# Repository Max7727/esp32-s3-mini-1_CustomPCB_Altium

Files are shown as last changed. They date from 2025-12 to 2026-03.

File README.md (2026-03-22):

# esp32-s3-mini-1_CustomPCB_Altium
Integrating an ESP32-S3-Mini-1 module into a custom PCB design

ESP32-S3-MINI-1 module - (Xtensa® dual-core 32-bit LX7) featuring 2.4 GHz Wi-Fi and Bluetooth 5 (LE).

I designed a custom PCB, centered around ESP32-S3-MINI-1 module based on reference schematics and guidelines from official manufactoror and various diffrent datasheets.

Used 4-layer stackup to provide dedicated GND planes for EMI shielding. Completed full manual route of all components, applied clearances and most common rules in PCB desing (including "rooms" altium special feature).

Features and capabilities:
* Digital communication - dual-interface: USB-C to UART bridge and USB-C to esp32 (ESP32-S3's native USB OTG capability)
* Power management - stable 3.3V power trace using a LDO Regulator, implemented polygon pours for both power and GND.
* ESD protection circuits- TVS diode protection to protect the internal silicon from electrostatic.
* 24-pin headers (Header 1x24) providing access to the full suite of GPIOs, SPI, I2C, and PWM pins.
* On-board status LEDs and tactile boot and reset switches
* Boot/reset circuits using NPN transistors.
* Dual Power Input Protection - designed the power stage to safely handle power from the USB-C connector while maintaining thermal stability through the LDO regulator ???
* Differential Pair Implementation (Impedance Control) - controlled trace lengths and widths to maintain target impedance 90 ohms, in order to reject common-mode noise and reduce EMI radiation.

* **Check out the description for commits for more details on the work process.**

# Schematics

<p align="center">
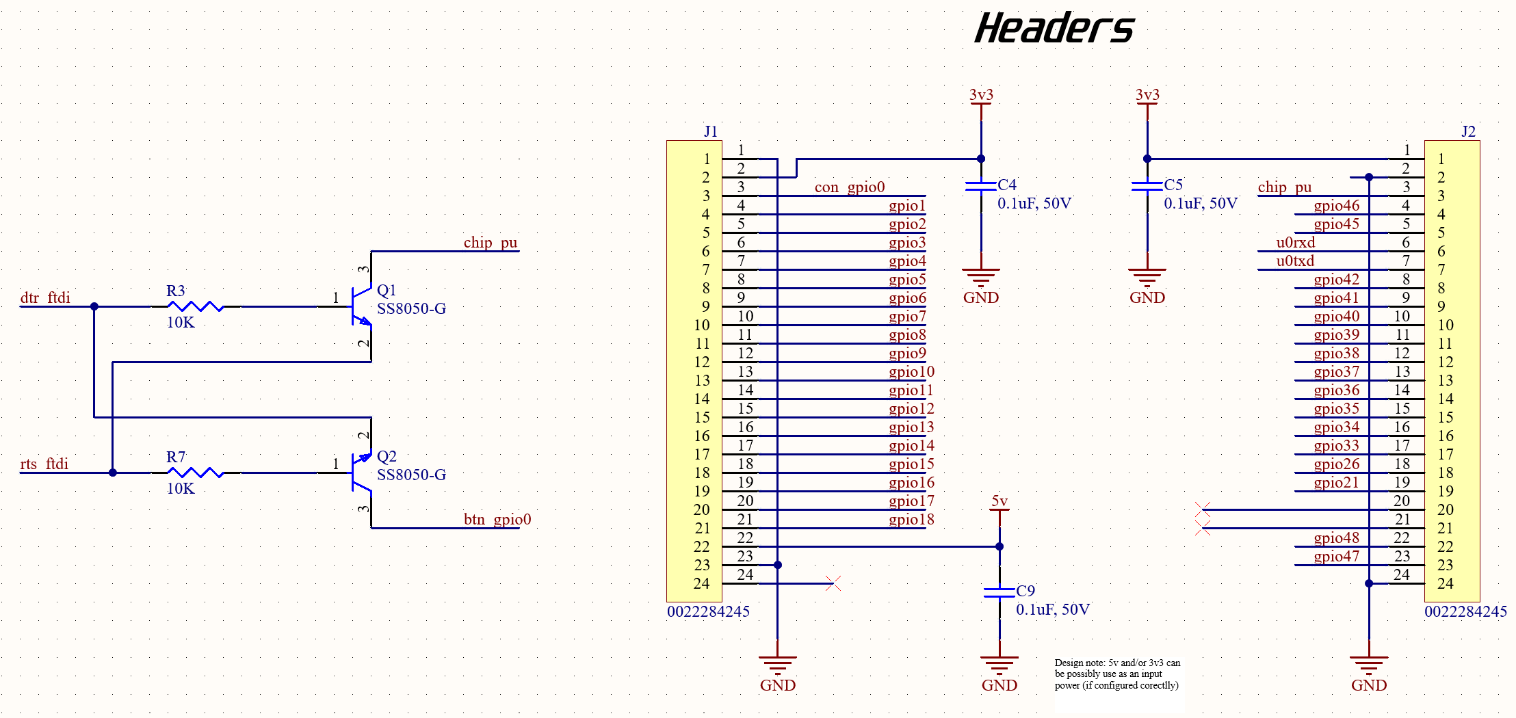
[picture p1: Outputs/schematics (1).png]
  
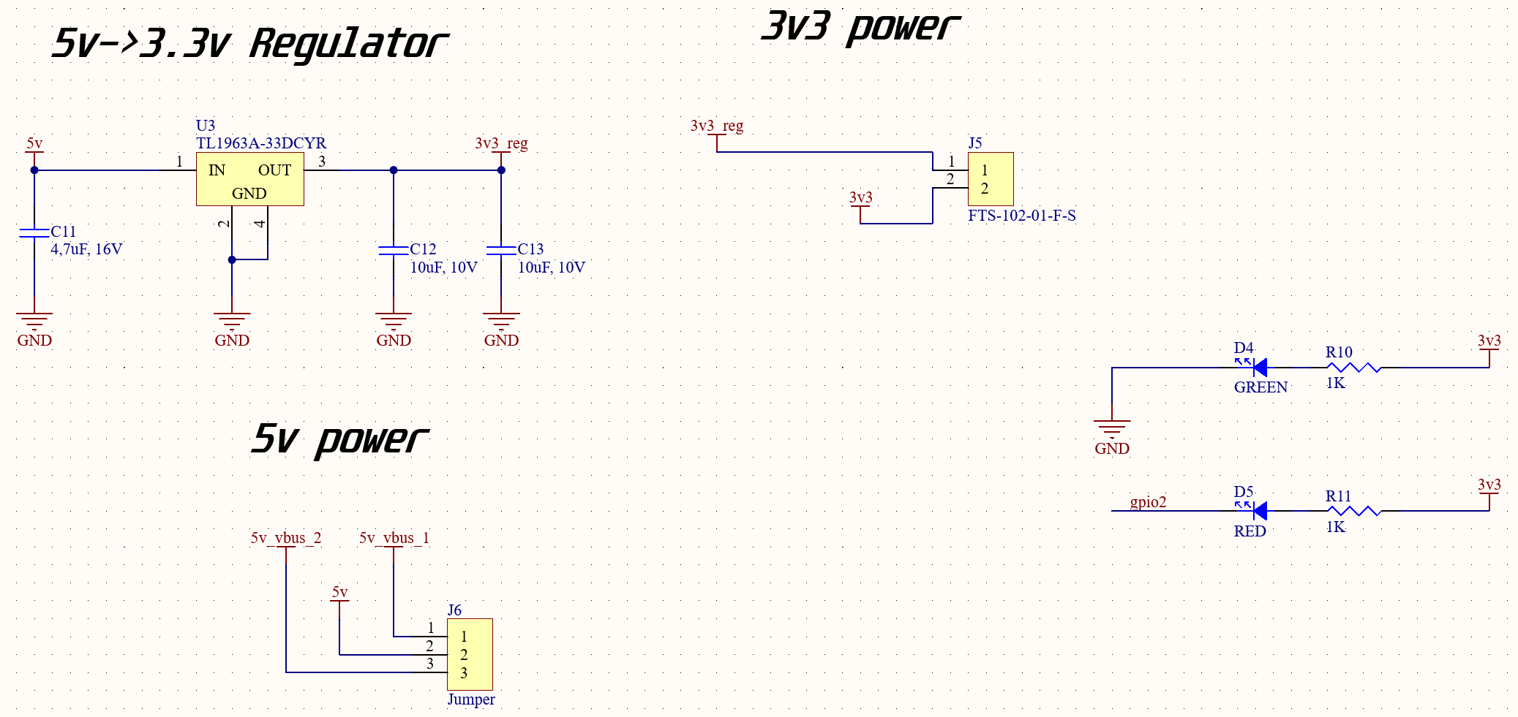
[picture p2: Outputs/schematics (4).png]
  
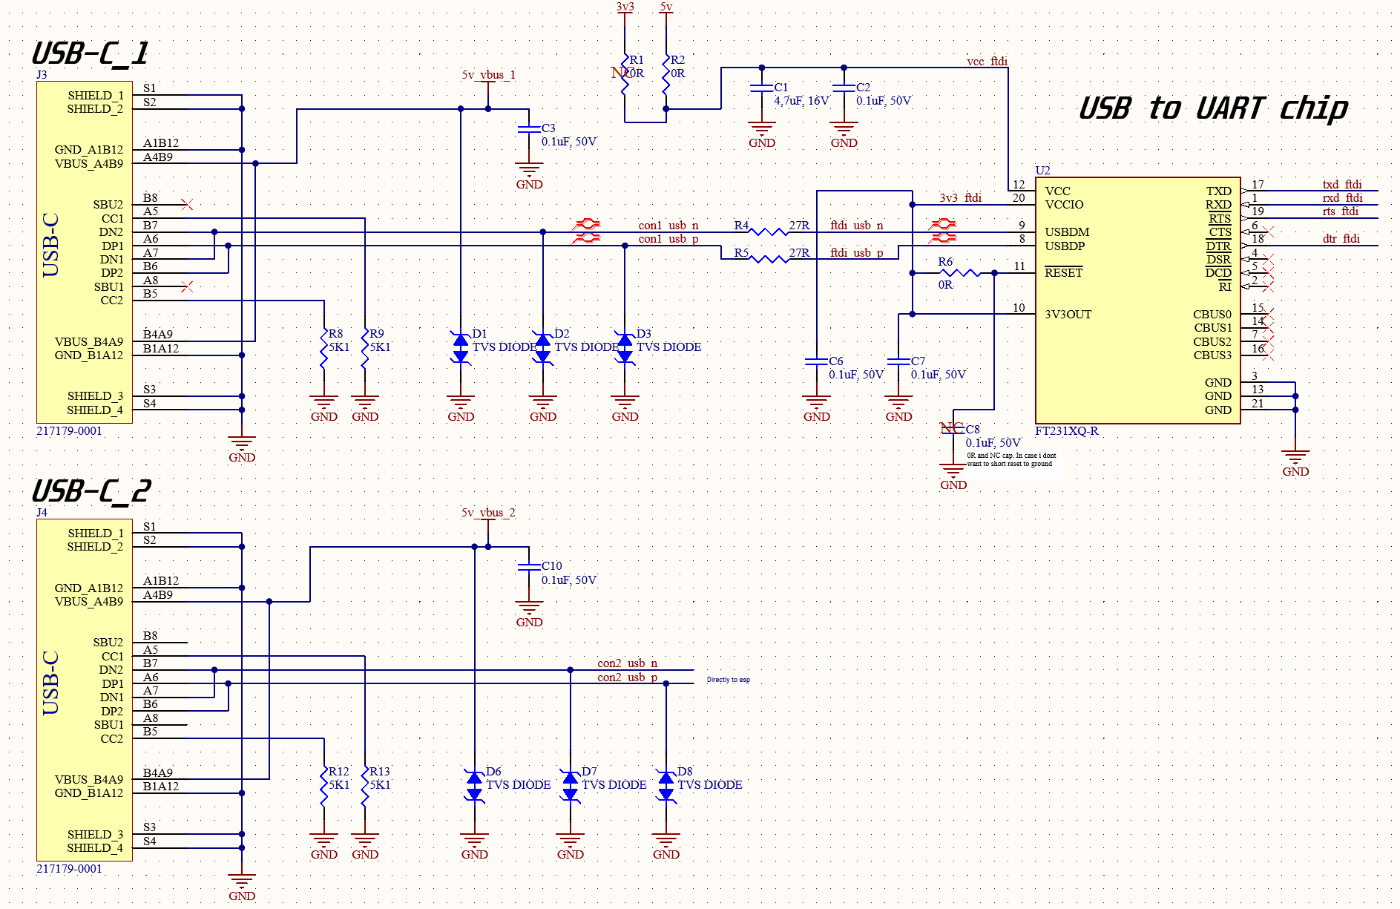
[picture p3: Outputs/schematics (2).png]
  
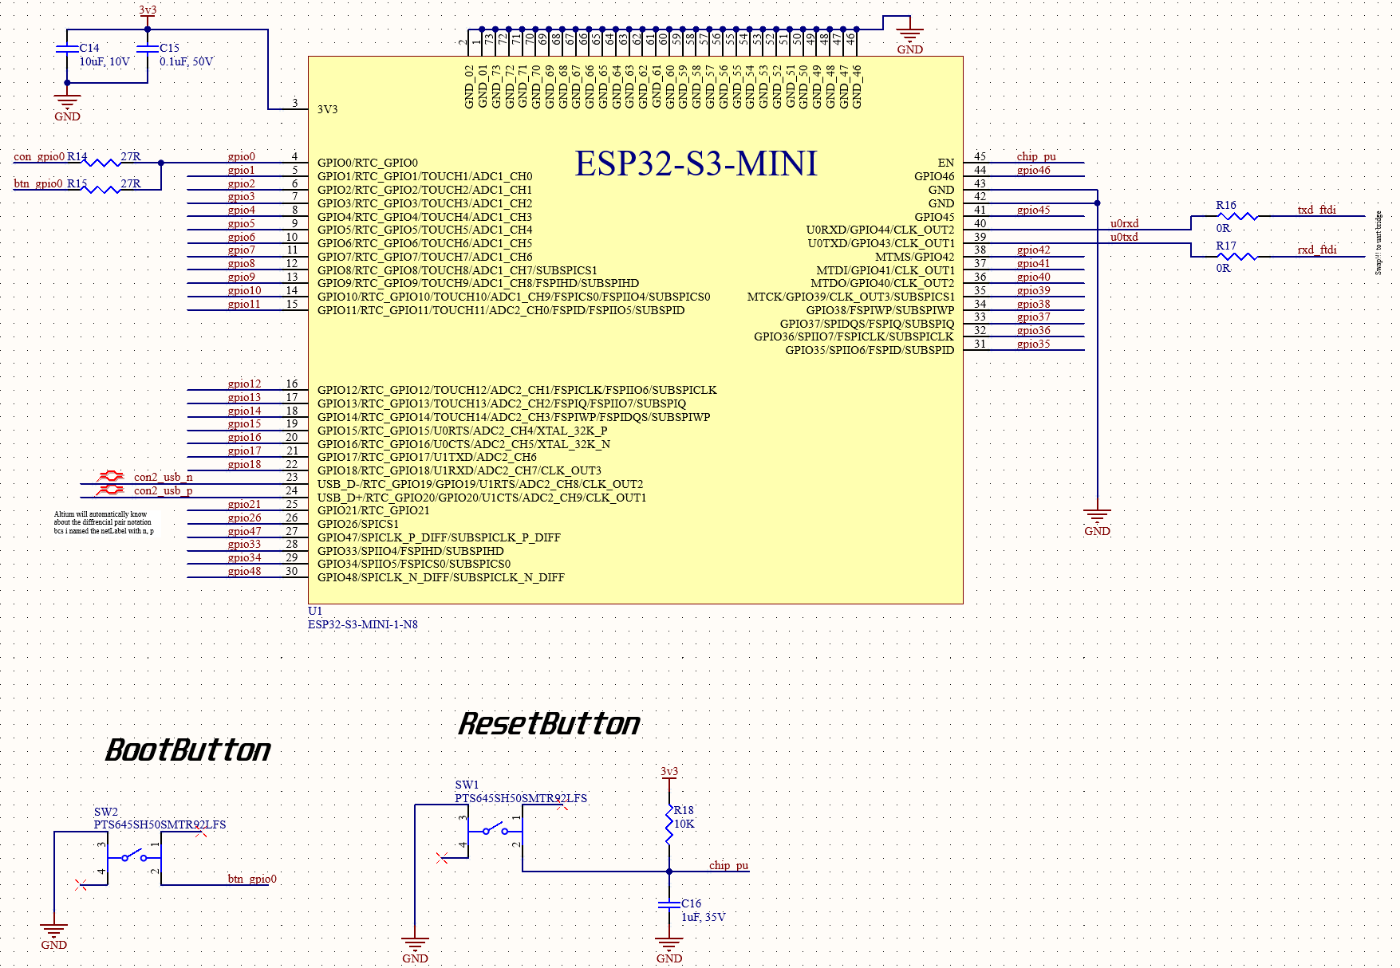
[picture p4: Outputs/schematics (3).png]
  
</p>

# PCB

### Top Layer
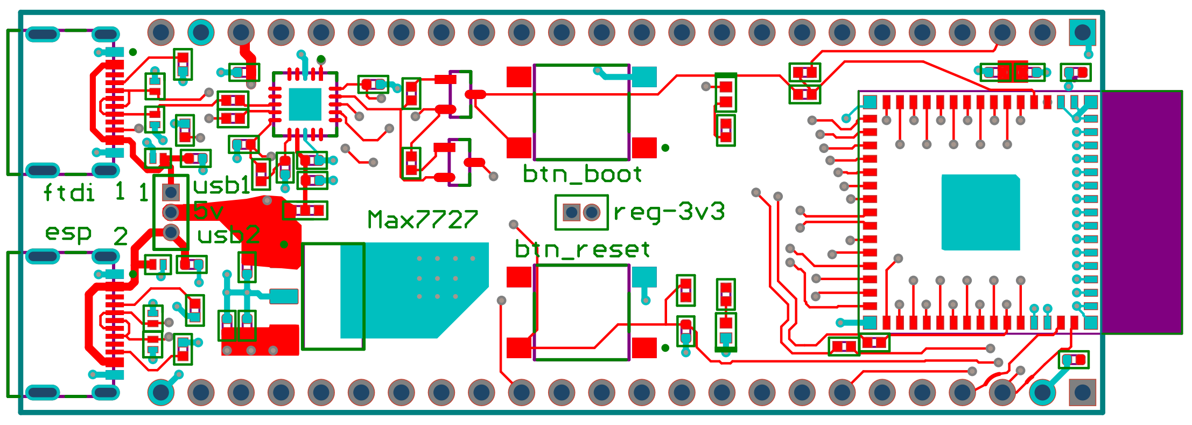
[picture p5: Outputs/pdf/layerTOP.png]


### Bottom Layer
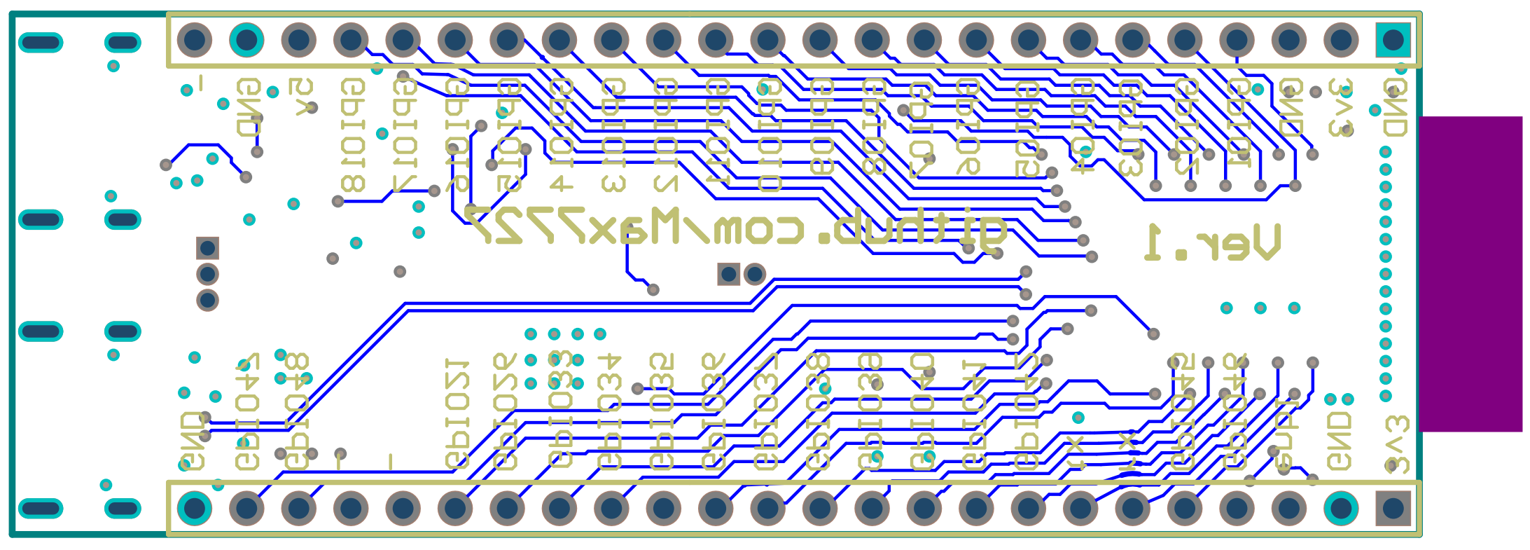
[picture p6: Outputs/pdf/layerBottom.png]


### Pwer and GND layers
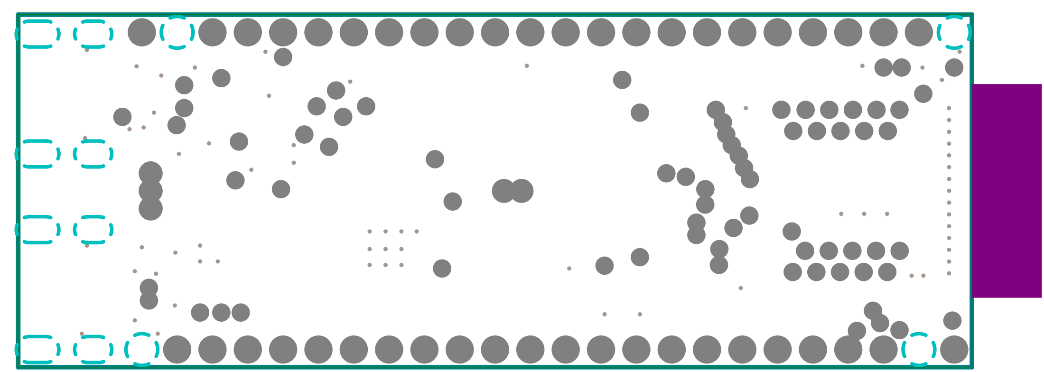
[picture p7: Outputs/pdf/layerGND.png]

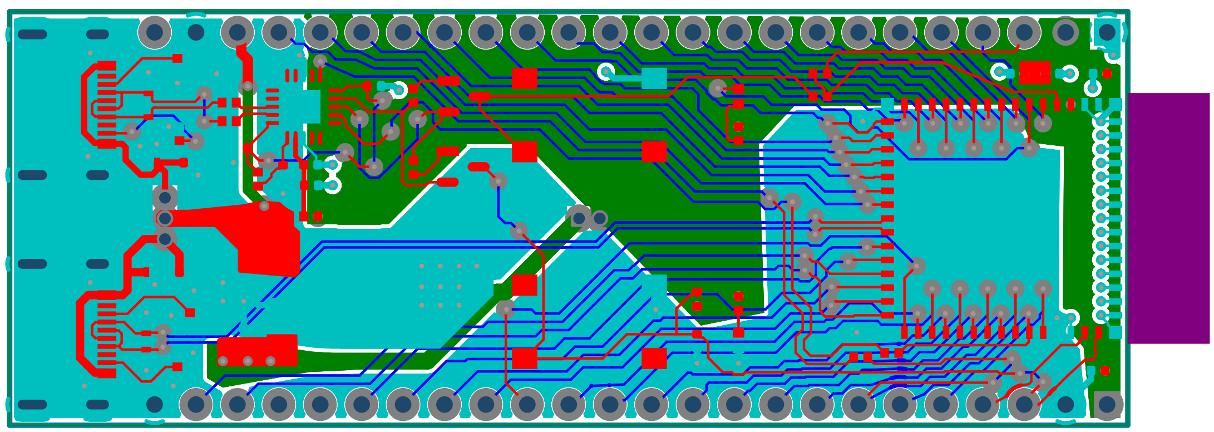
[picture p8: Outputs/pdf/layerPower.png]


### All layers together
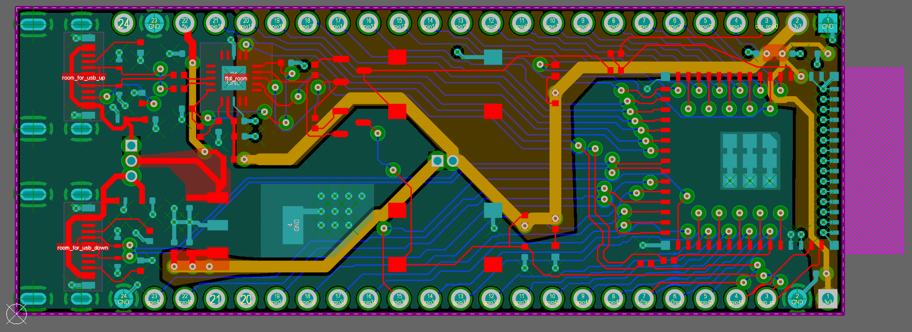
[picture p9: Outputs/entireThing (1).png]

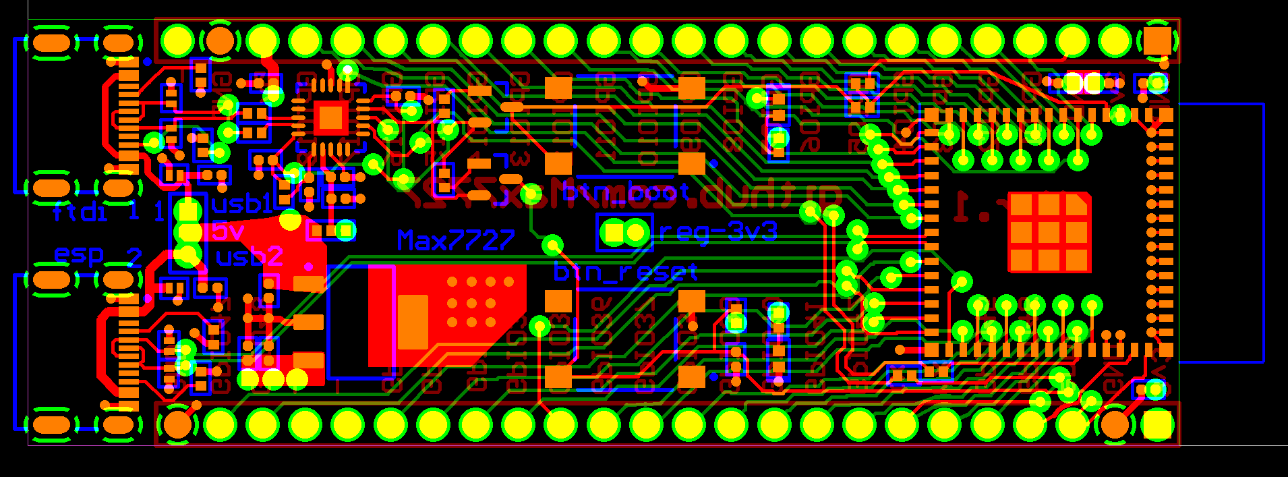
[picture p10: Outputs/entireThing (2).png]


### Top View
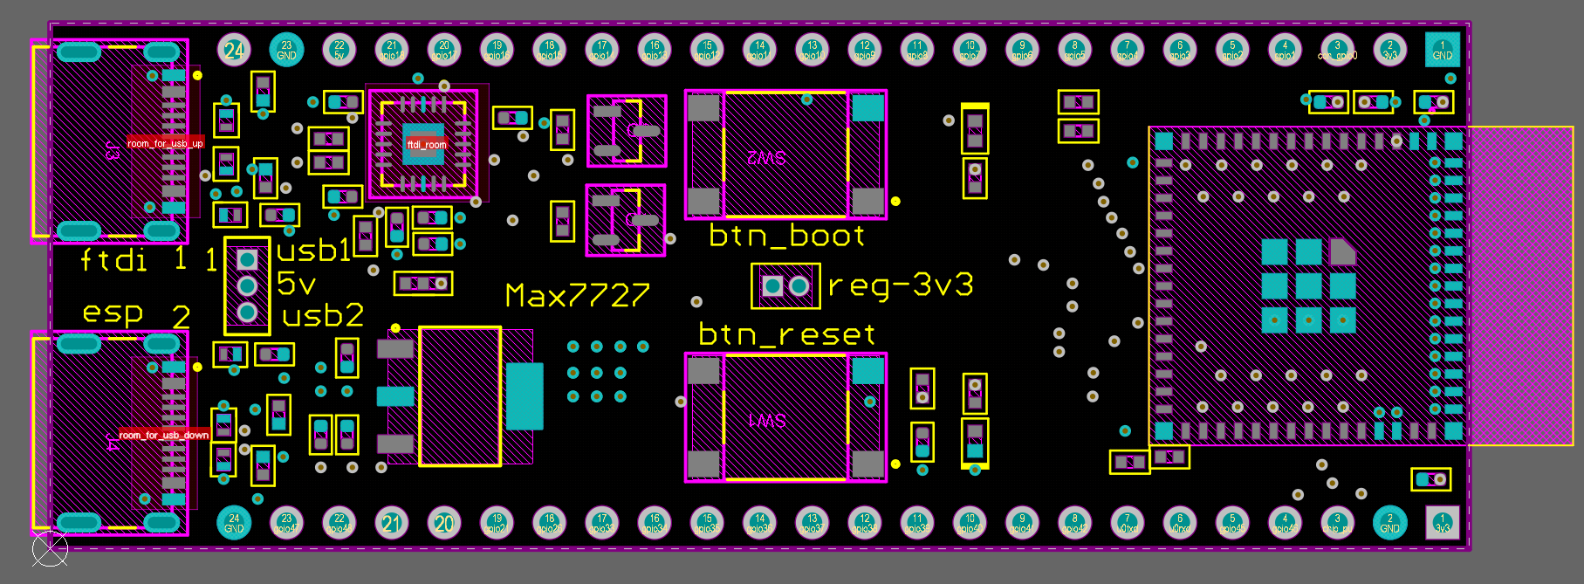
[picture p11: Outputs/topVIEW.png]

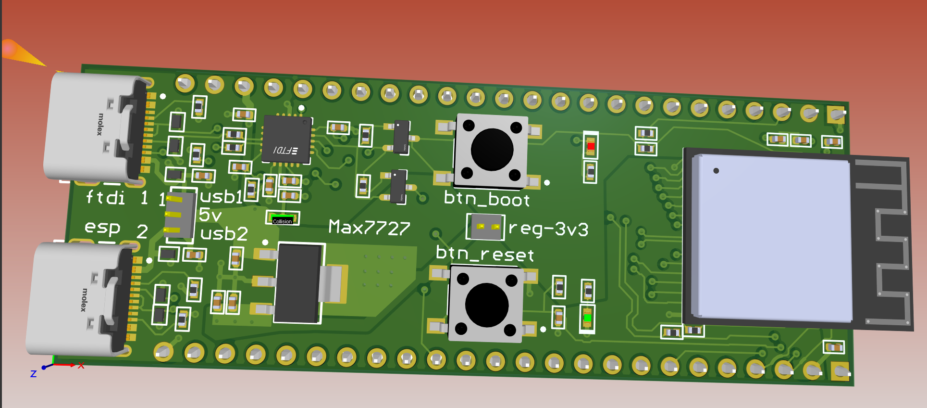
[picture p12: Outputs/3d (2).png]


### Bottom View 

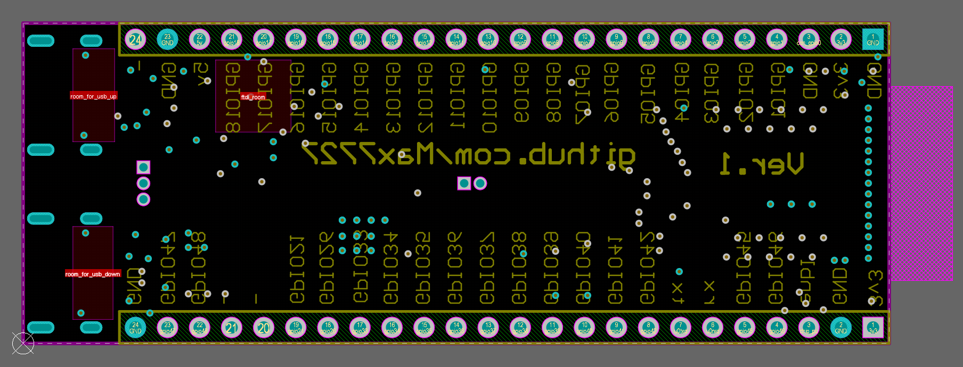
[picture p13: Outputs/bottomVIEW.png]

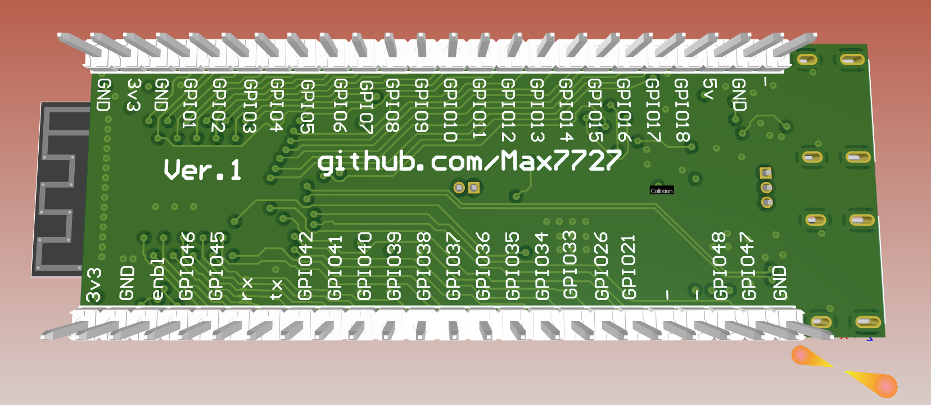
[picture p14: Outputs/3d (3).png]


### Overall look
<p align="center">
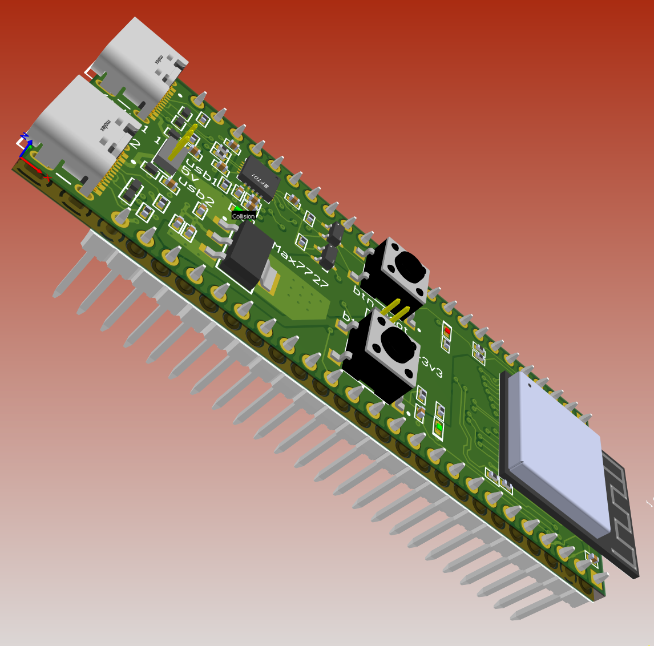
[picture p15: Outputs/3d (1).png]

</p>

* **Check out the description for commits for more details on the work process.**

Altium 25.8.1

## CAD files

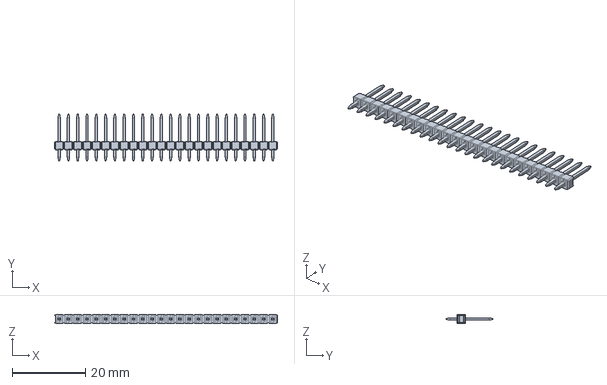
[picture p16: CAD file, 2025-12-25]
Res/Header_1x24.stp
61.0 x 12.8 x 2.49 mm

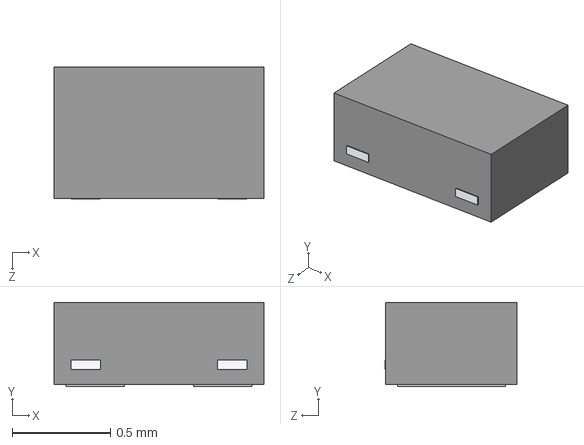
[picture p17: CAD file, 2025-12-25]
Res/TvsDiode.stp
1.07 x 0.43 x 0.675 mm

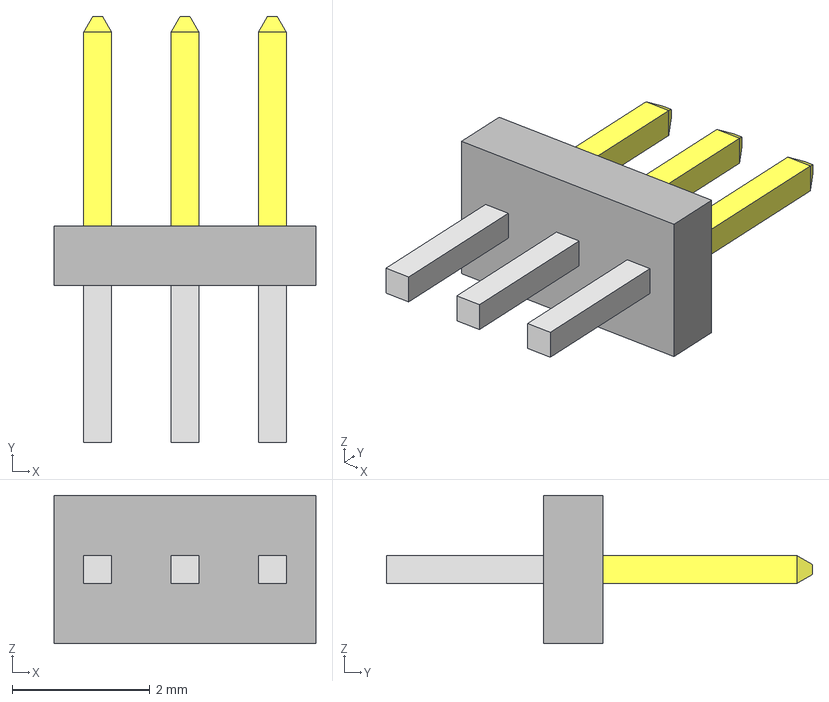
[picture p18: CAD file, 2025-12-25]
Res/Header_3x1.stp
3.81 x 6.20 x 2.16 mm
FTS-103-01-F-S_body
FTS-103-01-F-S_pins1
FTS-103-01-F-S_pins2

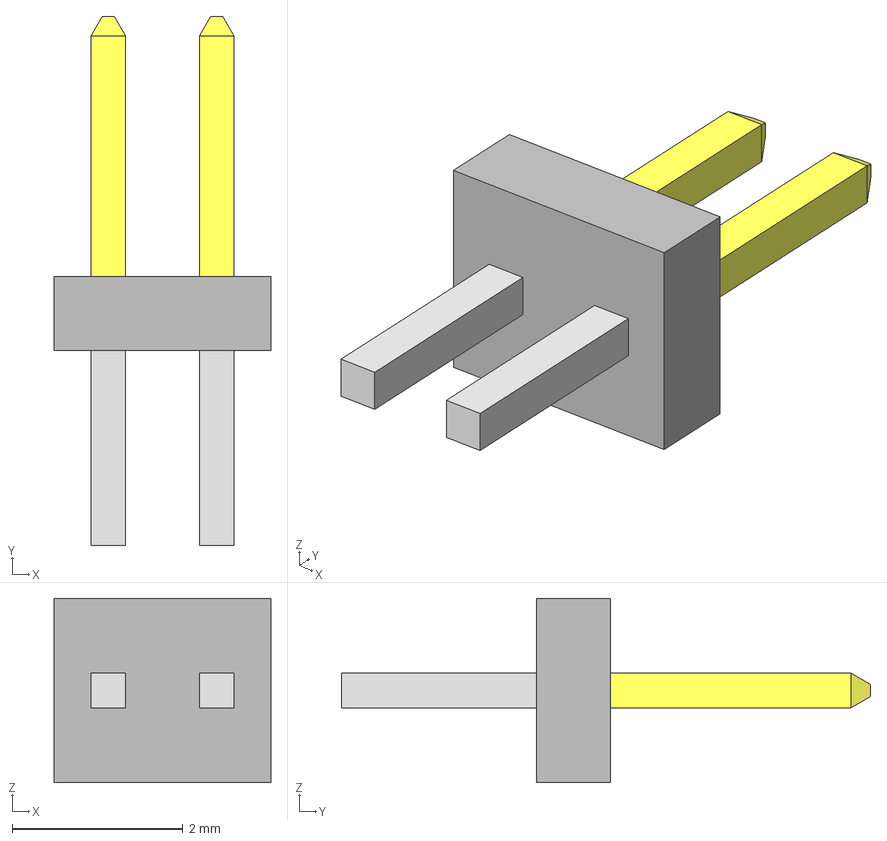
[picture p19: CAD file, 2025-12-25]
Res/Header2x1.stp
2.54 x 6.20 x 2.16 mm
FTS-102-01-F-S_body
FTS-102-01-F-S_pins1
FTS-102-01-F-S_pins2

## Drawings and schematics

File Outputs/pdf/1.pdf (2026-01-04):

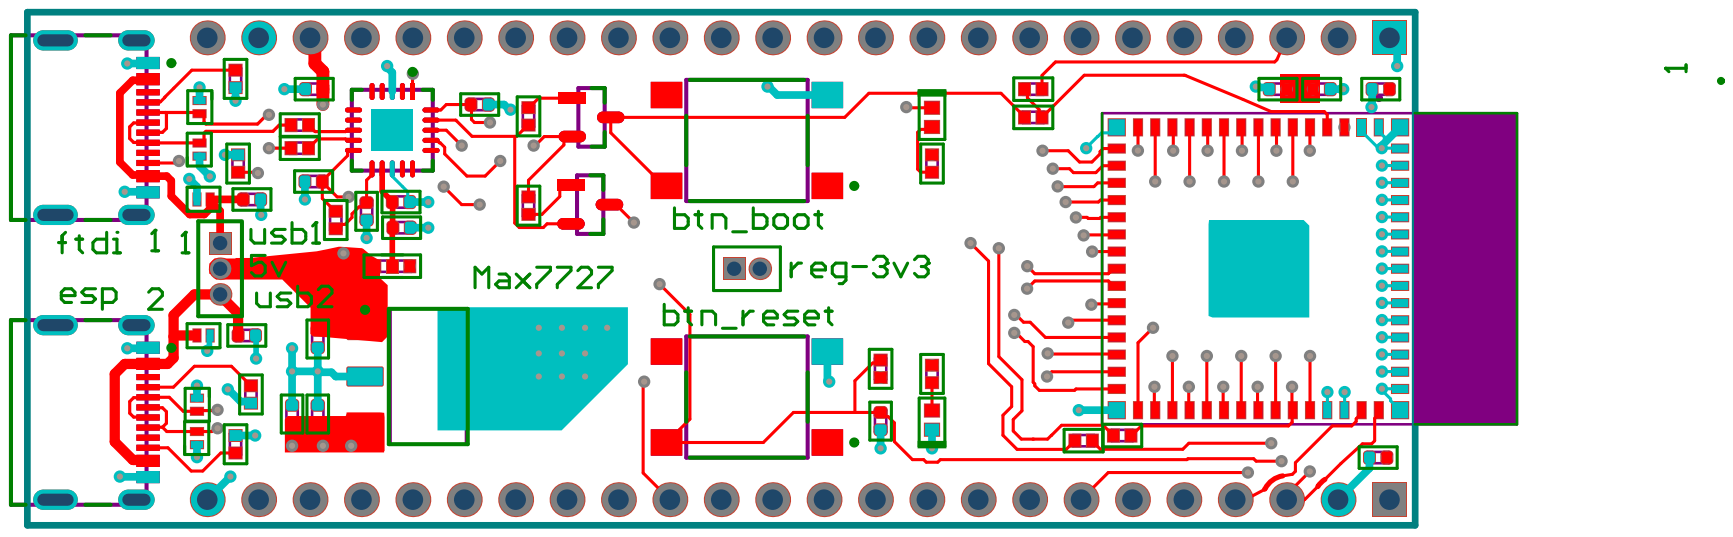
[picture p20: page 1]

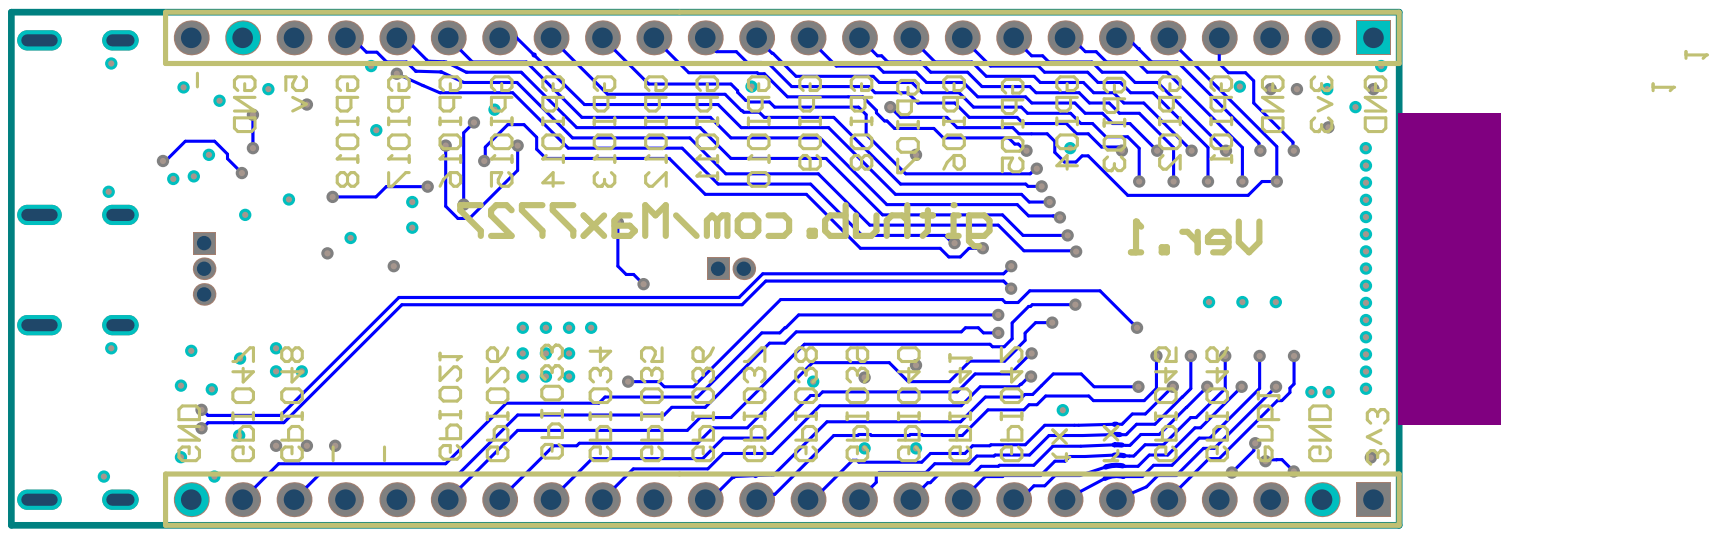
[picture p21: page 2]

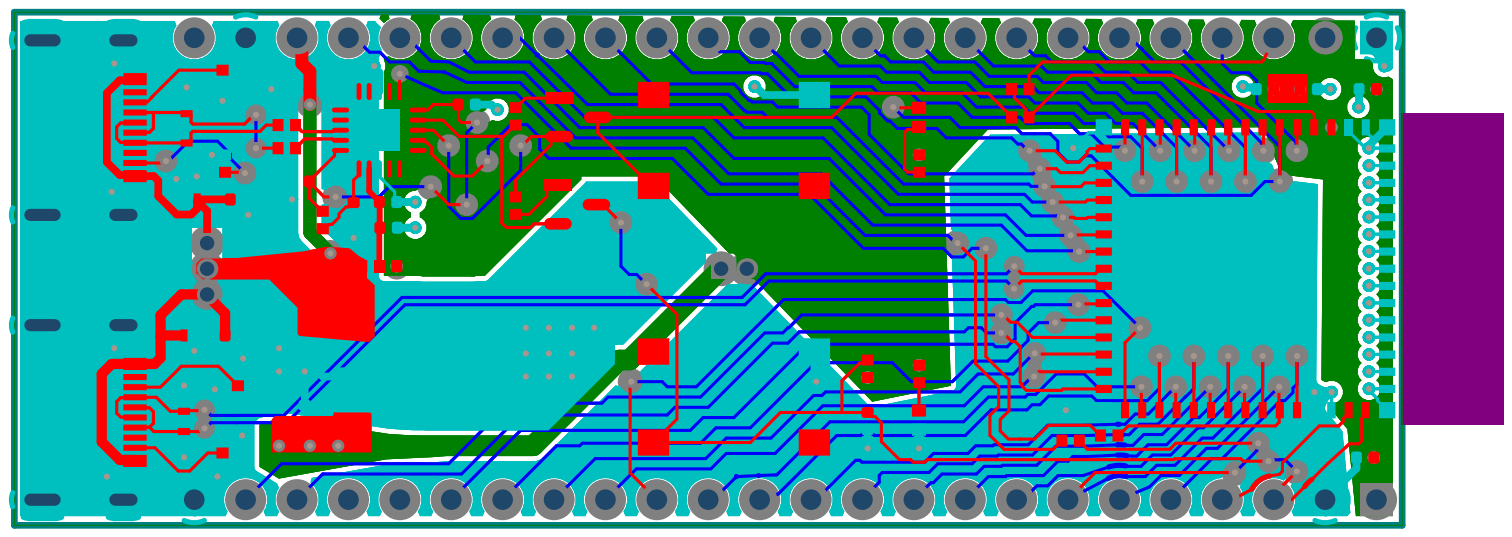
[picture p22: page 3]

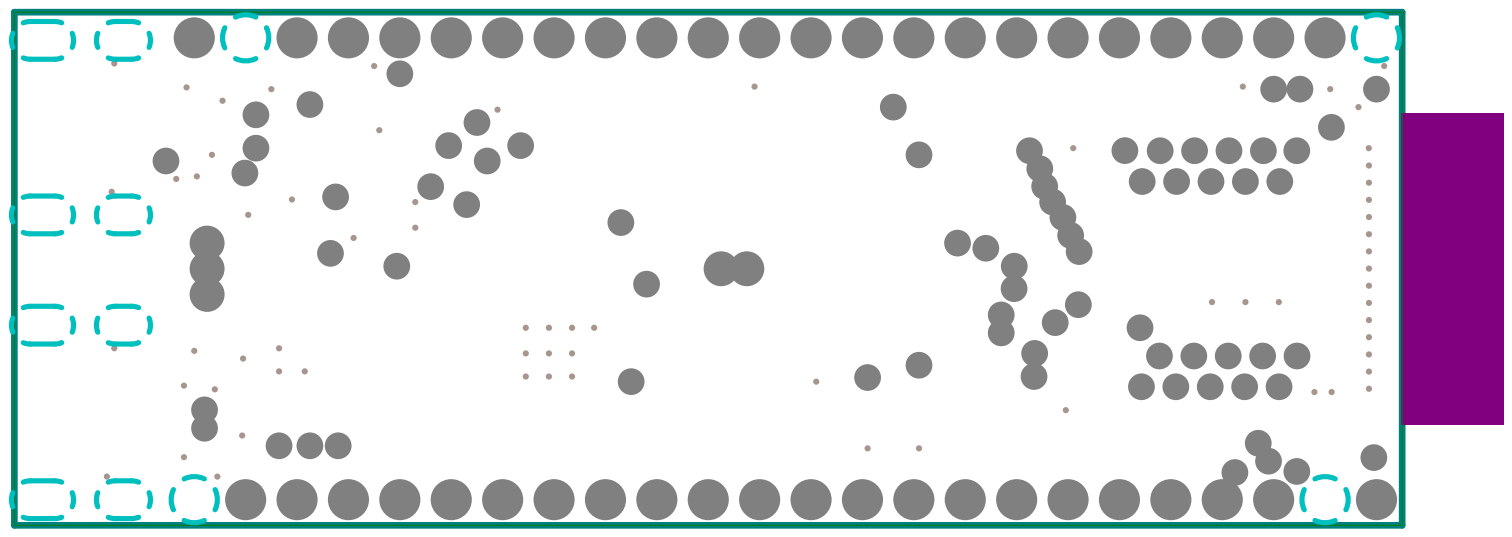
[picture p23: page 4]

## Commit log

2025-12-24 added symbols, schematics, connections for both buttons and esp module
    [Schlib1.SchLib, Sheet1.SchDoc]
2025-12-24 Added schematics, symbols, connections for both the usb-c connectors
    [Schlib1.SchLib, Sheet1.SchDoc]
2025-12-24 added ftdi usb to uart chip (symbols, connections )
    FT231X (USB to FULL HANDSHAKE UART IC)
    [PCB1.PcbDoc, Schlib1.SchLib, Sheet1.SchDoc]
2025-12-25 Added headers, power management, leds ...
    - finished connecting and configuring usb to uart chip.
    - added and conected:
    both headers, regulator, 5v and 3.3v power, boot and user leds.
    [Schlib1.SchLib, Sheet1.SchDoc]
2025-12-25 Added annotations via "annotate schematics"
    Automatically assigned unique designators.
    [Sheet1.SchDoc, esp32-s3-mini-1_CustomPCB_Altium.PrjPcb]
2025-12-25 Validated pcb project - schematics ok :)
    used "Validated pcb project" menu in altium, fixed all the errors.
    Compile successful :)
    [Sheet1.SchDoc]
2025-12-25 creating footprints, placing and aligning 3d models
    downloaded and added some footprints to my pcbLibrary.
    corrected some of downloaded footprints.
    assigned all the symbols from schLib to matching footprints.
    Using datasheets manually created :
    24x1 pin header footprint from scratch using 'footprint wizard', aligned its 3d model;
    3x1 conn header footprint from scratch using 'footprint wizard', aligned its 3d model;
    tvs diode footprint from scratch using 'footprint wizard', aligned its 3d model;
    [Header2x1.stp, Header_1x24.stp, Header_3x1.stp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]
2025-12-27 Finished footprints
    Finished footprints - ready for pcb layout in pcbDoc
    [PcbLib1.PcbLib, Schlib1.SchLib, Sheet1.SchDoc]
2025-12-27 Initialized my pcbDoc
    defined board shape from datasheet, placed some components
    [PCB1.PcbDoc, PcbLib1.PcbLib, Schlib1.SchLib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]
2025-12-27 pcbLayout in progress
    placed some components
    created my layerSets
    [PCB1.PcbDoc, PcbLib1.PcbLib]
2025-12-27 Placed some more components in pcbDoc
    changed GND net color,
    place almost all the components,
    corrected different designators in symbol pins and its footprint.
    [PCB1.PcbDoc, PcbLib1.PcbLib, Schlib1.SchLib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]
2025-12-27 Finished placing components on the pcb
    All the components sit on the pcb now, next step - connecting them all
    [PCB1.PcbDoc]
2025-12-28 Setting rules for pcb layout
    Set some basic rules for my pcb, based on JLCPCB website (electrical clearence, routing width, routing vias size, solder mask expansion).
    Created special rule 'R1-R2_exception' for the NC components, to place them on top of each other.
    [PCB1.PcbDoc, PcbLib1.PcbLib, Schlib1.SchLib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]
2025-12-28 Started the layout, routing, managing layers
    1. created new layers via 'layer stack manager', used 'JLC04161H-3313 Stackup' info
    2. layer_3 changed to plane - GND
    3. connected some grounds and almost all esp pins
    [PCB1.PcbDoc]
2025-12-28 Updating pcbDoc
    Because of some violation, placed rectangular room in order to create special electrical minimum clearance rule 'WithinRoom('ftdi_room') ' for ftdi chip.
    Routed most of the connections using various routing modes.
    [PCB1.PcbDoc]
2026-01-02 Finished rough (preliminary) routing
    1. Routed all the components.
    2. Routed differential pairs. For my stackup from JLCPCB website ("JLC04161H-3313") using the following info: 4 layers, 1.6mil pcb thickness, 90ohm impedance, 8mil trace spacing; i determined trace width for my differential pairs: 6.12mil and 8mil gap.
    3. Managed to do it all on just 3 layers (forgot i had 4 layers in my disposal, didn't even need the 4th layer for routing). I am gonna fix it later and use all the layers.
    [PCB1.PcbDoc]
2026-01-03 Updating pcb
    rerouted power traces,
    fixed all the violations, including clearence violations via setting up rooms for usb connectors
    [PCB1.PcbDoc, esp32-s3-mini-1_CustomPCB_Altium.PrjPcb]
2026-01-03 Added polygons and some corrections
    polished the power connections;
    added polygons with assigned nets;
    added big polygons for 3v3 and gnd on the layer 2 (in polygon pour manager specified pour order for layer 2);
    added board shape mechanical layer.
    [PCB1.PcbDoc, PcbLib1.PcbLib, Schlib1.SchLib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]
2026-01-03 Update pcbDoc
    Added string descriptions to my board on both top and bottom overlay layers.
    Debugged some of the 'pcb rules and violations'.
    [PCB1.PcbDoc]
2026-01-03 Set impedance for signal tracks and fixed all the violations
    1. In 'design rule check' debugged and fixed all the 'pcb rules and violations'.
    2. adjusted width of signal traces for their impedance to be 50ohm,
    used the following pcb filter:
    (ObjectKind = 'Track') And ((Layer = 'LaYeR_4') OR (Layer = 'LaYeR_1')) And ((AsMils(Width) = 10) or (AsMils(Width) = 9))
    to select all the digital (signal) tracks and make them appropriate width to fit the impedance criteria => 6mil
    [PCB1.PcbDoc]
2026-01-04 generated outputs
    Generated gerber files, double checked them in ViewMate.
    Generated pdf files and images.
    [PCB1.PcbDoc, Sheet1.SchDoc, esp32-s3-mini-1_CustomPCB_Altium.PrjPcb]

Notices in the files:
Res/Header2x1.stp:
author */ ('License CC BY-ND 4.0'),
